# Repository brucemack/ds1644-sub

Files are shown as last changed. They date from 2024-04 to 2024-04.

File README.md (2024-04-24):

Overview
========
The goal of this project is to produce an adaptor board to allow a "modern" M48T35 NVRAM/RTC chip to be 
used where a
"vintage" DS1643/DS1644 used to be.  This is relevant for owners of S-COM
5K/6K/7K repeater controllers.  The old Dallas Semi parts are
hard to find in DIP format, and at this point their batteries are likely 
dead.

(Testing is still in process - more documentation will follow if this works.)

Here's what the board looks like:

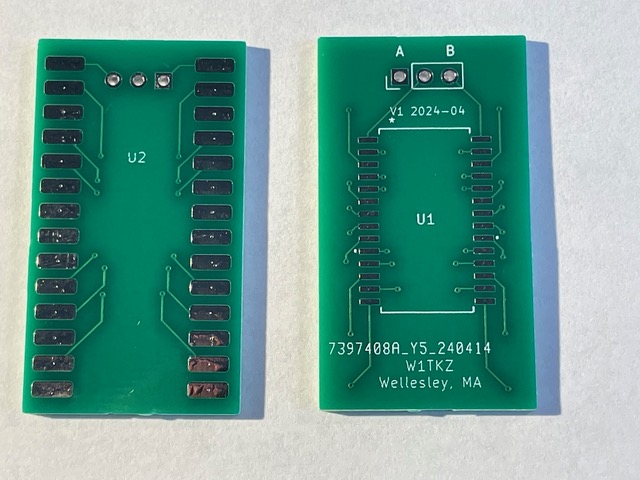
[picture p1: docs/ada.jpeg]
Adaptor


References
==========

* [M48T35 Datasheet](https://www.st.com/content/ccc/resource/technical/document/datasheet/group1/b6/56/b6/36/4d/38/4d/18/CD00000551/files/CD00000551.pdf/jcr:content/translations/en.CD000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)
* [DS1643 Datasheet](https://www.analog.com/media/en/technical-documentation/data-sheets/DS1643-DS1643P.pdf) - used in the 5K
* [DS1644 Datasheet](https://www.analog.com/media/cn/technical-documentation/data-sheets/2744.pdf) - used in the 7K

Photograph of DS1643 in an S-COM 5K to demonstrate that mechanical clearance isn't an issue around the chip.

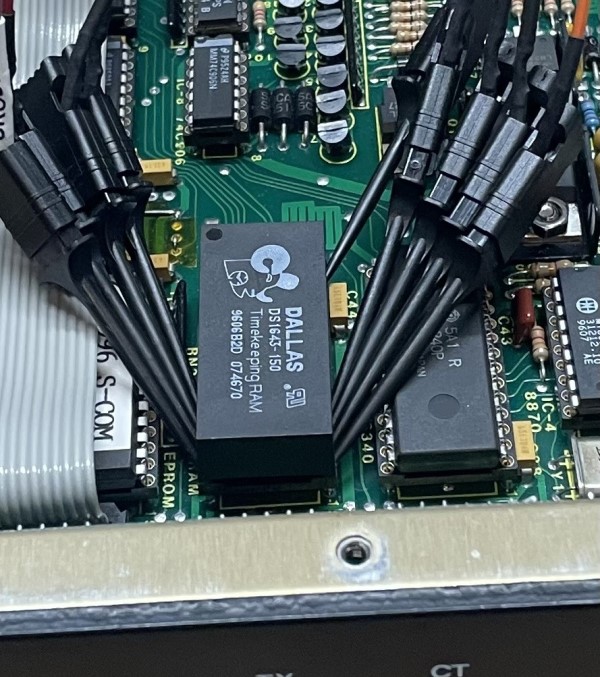
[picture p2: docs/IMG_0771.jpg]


Notes on Testing an Original DS1643
===================================

I have access to an S-COM 5K that has a DS1643 NVRAM/RTC chip in it. I've been using that 
to do some testing.  I pulled the DS1643 out of the controller and put it into my memory tester (see more detail on that below). 

The date code on the part is 1996.  It works fine!

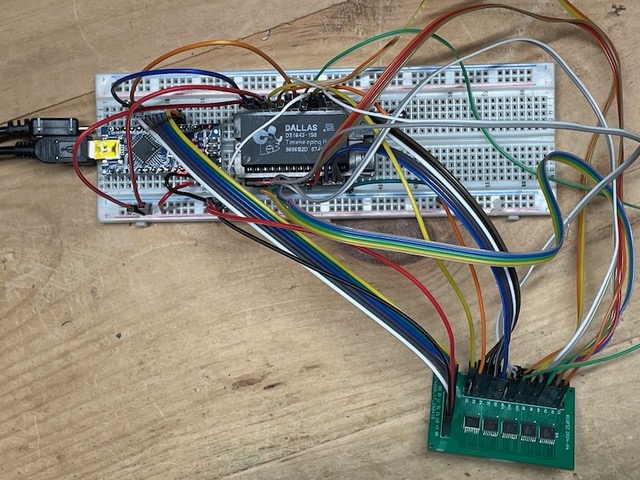
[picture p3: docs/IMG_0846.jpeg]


This chip is interesting in that the RTC is mapped into the 
very top few bytes of the NVRAM.  On the 8K part you need to read from locations 0x1ff9 to 0x1fff to get the time/date.  IMPORTANT: Remember that all numbers are in 
BCD format with the 1's digit in the low-order nibble and the 10's digit in the high-order nibble of each byte.

When I powered up the chip and read the time from the magic 
locations I was amazed to see that it was correct to within <2 hours after an unknown period
of time of non-use. Obviously, the battery is still good in this 
particular unit. :-)

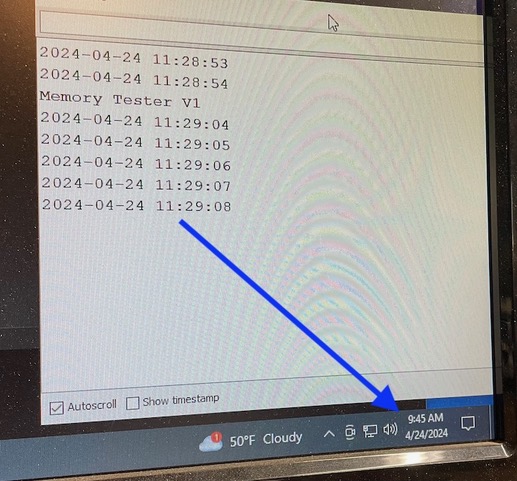
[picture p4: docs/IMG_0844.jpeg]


The S-COM 7K uses a 32K part. Everything should be the same,
except the memory map locations of the RTC are higher.

Notes Related to a Memory Tester
================================

A memory testing device was created to read/write/validate 5V RAM/PROM parts, along with any related adaptor boards. This could be used to test
that a chip/socket is working correctly or to make a copy of an NVRAM/EPROM/EEPROM. 

The tester can support 16 address lines, 8 bit-directional data lines, and three control lines (~OE, ~WE, ~CS, etc),
for a total of 27 signals.  Only 6 GPIO pins on a microcontroller are needed to drive the tester.

The testing cycle writes/reads different patterns into the 
memory chip to make sure there are no bad bits.

Here's what the tester PCB looks like:

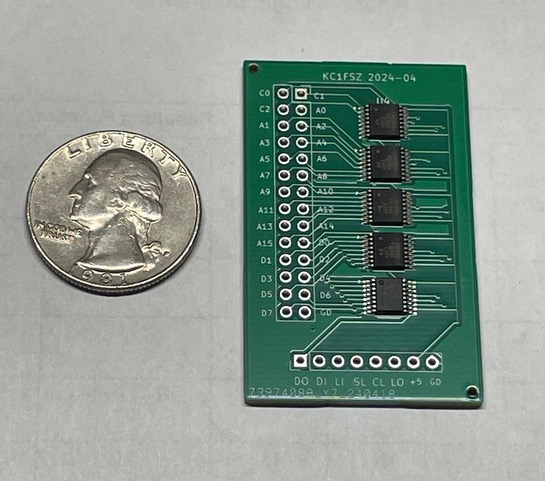
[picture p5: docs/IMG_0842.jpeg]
Tester1


Here it is wired into an Arduino Nano and a 28-pin ZIF socket
for testing:

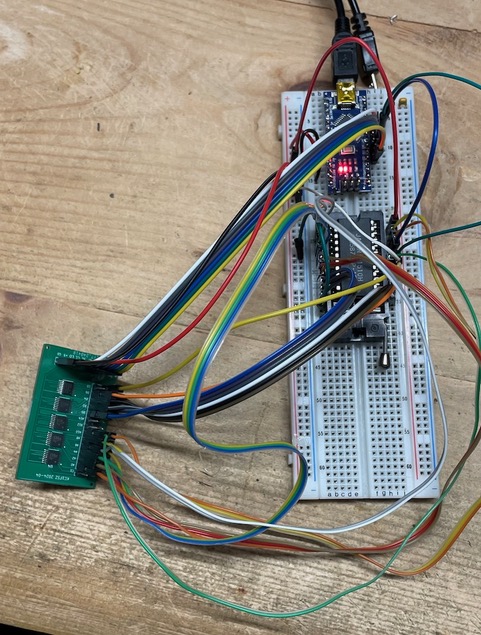
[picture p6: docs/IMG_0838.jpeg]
Tester2


Here's a vintage [Toshiba 2K SRAM chip](http://matthieu.benoit.free.fr/cross/data_sheets/TMM2016AP.pdf) that was tested successfully:

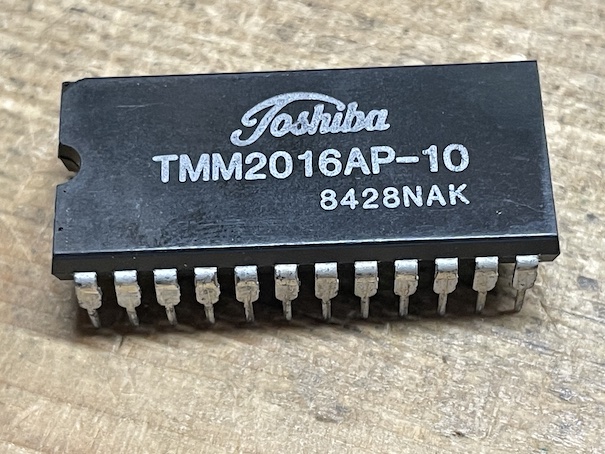
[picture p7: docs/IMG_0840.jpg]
SRAM


Judging from [this databook](http://www.bitsavers.org/components/toshiba/_dataBook/1983_Toshiba_MOS_Memory.pdf) an the date code
on that chip I'm assuming it's a 1984 part.  We've come a long
way in 40 years!

Tester Shift Register Chain Layout
----------------------------------
       
       |    Control     |   Address Low   |  Address High   |    Data Out     |   Data In      |
       +----------------+-----------------+-----------------+-----------------+----------------+
        C C C x x x x O   A A A A A A A A   A A A A A A A A   O O O O O O O O   I I I I I I I I  
        0 1 2         E   0 0 0 0 0 0 0 0   0 0 1 1 1 1 1 1   0 1 2 3 4 5 6 7   0 1 2 3 4 5 6 7
                          0 1 2 3 4 5 6 7   8 9 0 1 2 3 4 5

                                    =========== DATA FLOW ==========>    

Notes
* Data flows from left to right.
* There is no hand-off between O7 and I0.
* The high-order bit of the Control register (OE) controls the -OE of the Data Out register. So
you must write a zero into this bit when generating a write into a memory device.

Tester Control Interface
------------------------

(From left to right)

* Pin 1: Data Out - High-order bit out of the Data In register (i.e. I7 in the above diagram)
* Pin 2: Data In - Low-order bit into the Control register (i.e. C0 in the above diagram)
* Pin 3: Latch In (+) - Only relevant for the Data In register.  Rising edge locks the memory device output 
into the Data In register.  Make sure that shift/load is set to 1 before doing this.
* Pin 4: Shift/Load - Only relevant for the Data In register.  Issue a zero pulse after the Latch In clock
to move data into the shift register, preparing to shift out the data that was read.
* Pin 5: Clock (+) - Rising edge shifts one position to the right.  Make sure that shift/load is set to 0 before
doing this.
* Pin 6: Latch Out (+) - Rising edge makes the contents of the Control, Address Low, Address High, and Data Out
registers visible to the memory device.  
* Pin 7: 5V
* Pin 8: Ground

Copyright
=========

Copyright (C) 2024 - Bruce MacKinnon

This work is covered under the terms of the GNU Public License (V3). Please consult the LICENSE file for more information.

This work is being made available for non-commercial use. Redistribution, commercial use or sale of any part is prohibited.

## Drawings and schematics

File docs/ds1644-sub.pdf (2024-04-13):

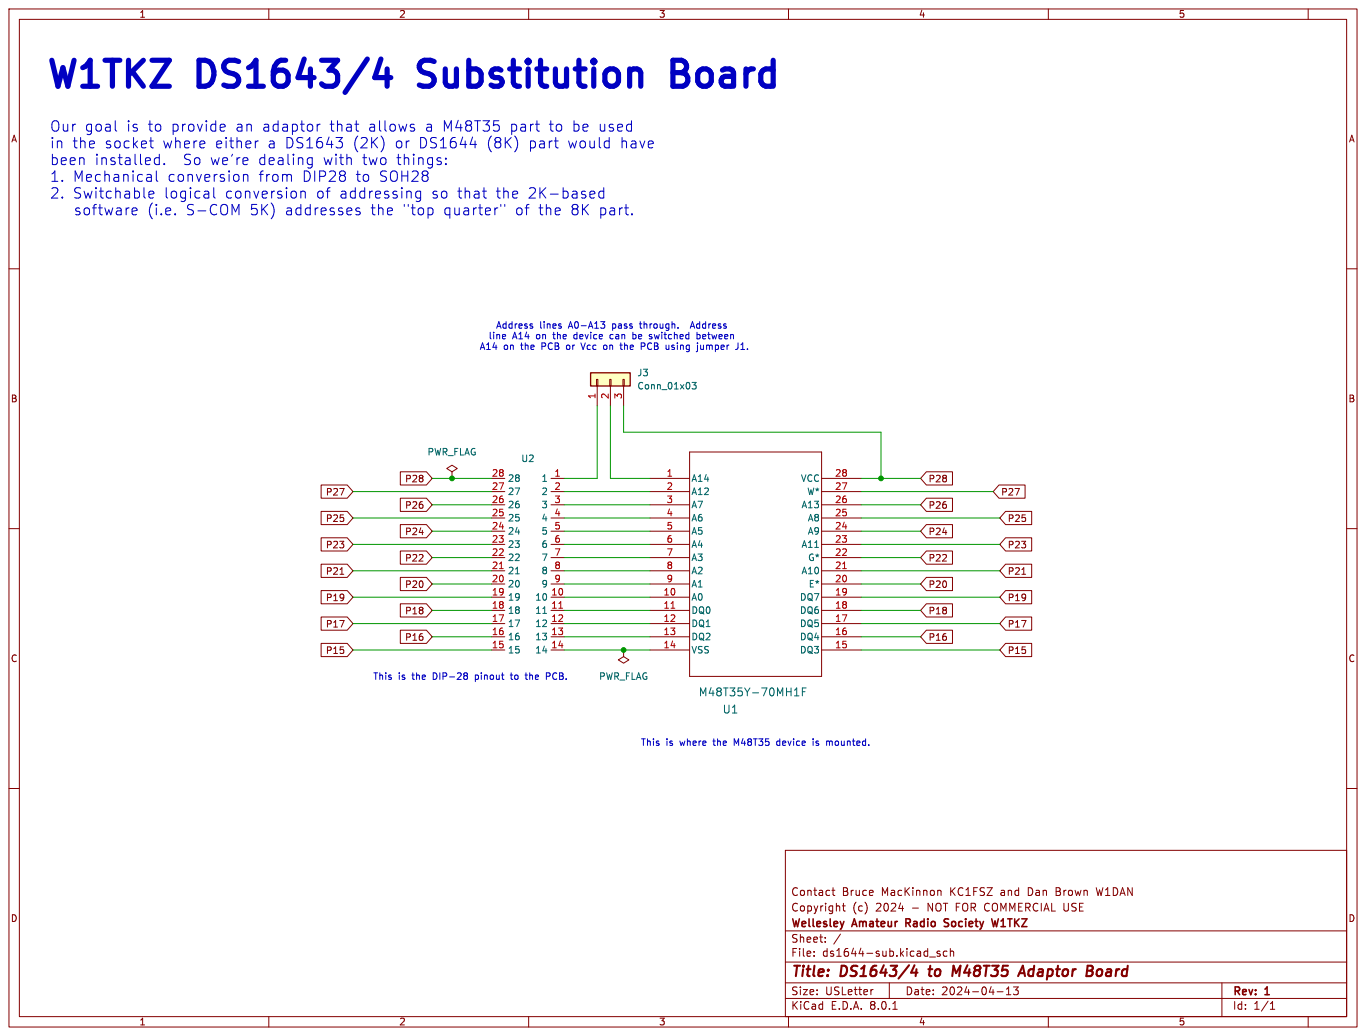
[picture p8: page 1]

Our goal is to provide an adaptor that allows a M48T35 part to be used
in the socket where either a DS1643 (2K) or DS1644 (8K) part would have

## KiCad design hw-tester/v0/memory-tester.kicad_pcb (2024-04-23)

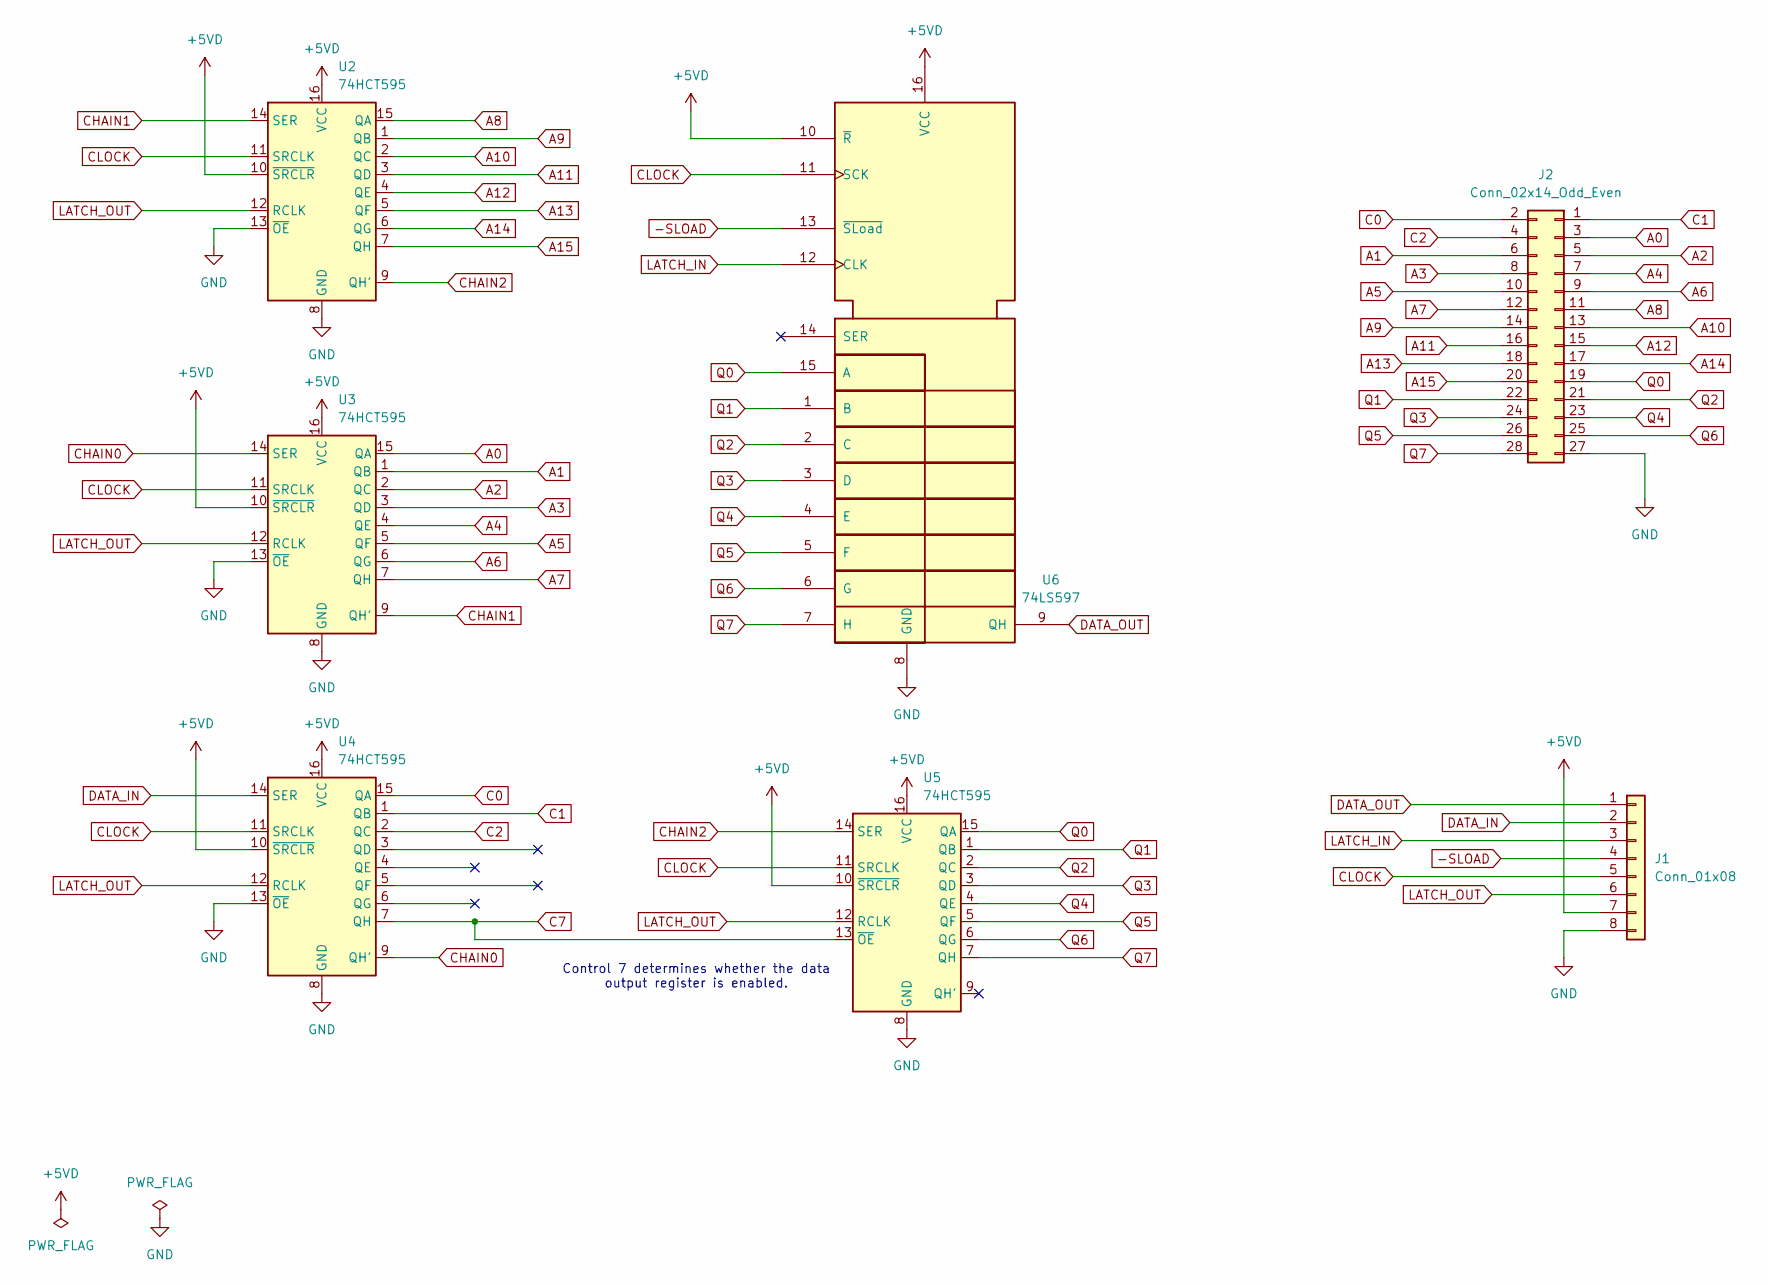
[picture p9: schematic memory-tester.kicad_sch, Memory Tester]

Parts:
J1: Conn_01x08; PinHeader_1x08_P2.54mm_Vertical
J2: Conn_02x14_Odd_Even; PinSocket_2x14_P2.54mm_Vertical
U2, U3, U4, U5: 74HCT595; TSSOP-16_4.4x5mm_P0.65mm; LCSC C273642
U6: 74LS597; TSSOP-16_4.4x5mm_P0.65mm; LCSC C5444304

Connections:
+5VD: J1.7, U2.10 (~SRCLR), U2.16 (VCC), U3.10 (~SRCLR), U3.16 (VCC), U4.10 (~SRCLR), U4.16 (VCC), U5.10 (~SRCLR), U5.16 (VCC), U6.10 (~R), U6.16 (VCC)
-SLOAD: J1.4, U6.13 (~SLoad)
A0: J2.3, U3.15 (QA)
A1: J2.6, U3.1 (QB)
A2: J2.5, U3.2 (QC)
A3: J2.8, U3.3 (QD)
A4: J2.7, U3.4 (QE)
A5: J2.10, U3.5 (QF)
A6: J2.9, U3.6 (QG)
A7: J2.12, U3.7 (QH)
A8: J2.11, U2.15 (QA)
A9: J2.14, U2.1 (QB)
A10: J2.13, U2.2 (QC)
A11: J2.16, U2.3 (QD)
A12: J2.15, U2.4 (QE)
A13: J2.18, U2.5 (QF)
A14: J2.17, U2.6 (QG)
A15: J2.20, U2.7 (QH)
C0: J2.2, U4.15 (QA)
C1: J2.1, U4.1 (QB)
C2: J2.4, U4.2 (QC)
C7: U4.7 (QH), U5.13 (~OE)
CHAIN0: U3.14 (SER), U4.9 (QH')
CHAIN1: U2.14 (SER), U3.9 (QH')
CHAIN2: U2.9 (QH'), U5.14 (SER)
CLOCK: J1.5, U2.11 (SRCLK), U3.11 (SRCLK), U4.11 (SRCLK), U5.11 (SRCLK), U6.11 (SCK)
DATA_IN: J1.2, U4.14 (SER)
DATA_OUT: J1.1, U6.9 (QH)
GND: J1.8, J2.27, U2.8 (GND), U2.13 (~OE), U3.8 (GND), U3.13 (~OE), U4.8 (GND), U4.13 (~OE), U5.8 (GND), U6.8 (GND)
LATCH_IN: J1.3, U6.12 (CLK)
LATCH_OUT: J1.6, U2.12 (RCLK), U3.12 (RCLK), U4.12 (RCLK), U5.12 (RCLK)
Q0: J2.19, U5.15 (QA), U6.15 (A)
Q1: J2.22, U5.1 (QB), U6.1 (B)
Q2: J2.21, U5.2 (QC), U6.2 (C)
Q3: J2.24, U5.3 (QD), U6.3 (D)
Q4: J2.23, U5.4 (QE), U6.4 (E)
Q5: J2.26, U5.5 (QF), U6.5 (F)
Q6: J2.25, U5.6 (QG), U6.6 (G)
Q7: J2.28, U5.7 (QH), U6.7 (H)

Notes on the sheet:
Control 7 determines whether the data output register is enabled.

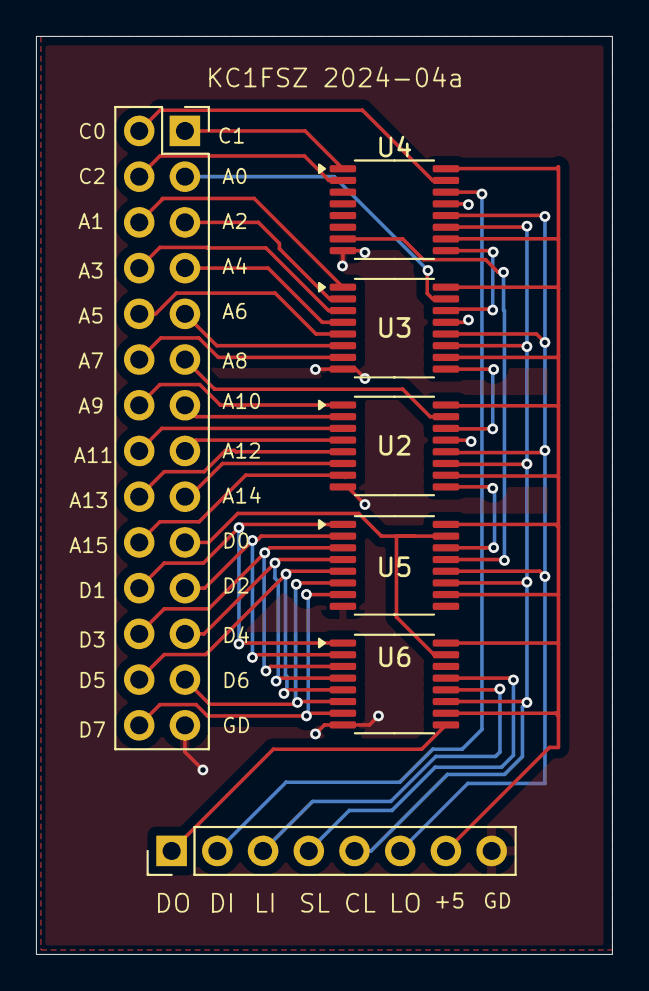
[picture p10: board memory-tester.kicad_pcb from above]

Board: 2 copper layers, 32.0 x 51.0 mm, 7 parts (0 on the bottom side), 39 nets.

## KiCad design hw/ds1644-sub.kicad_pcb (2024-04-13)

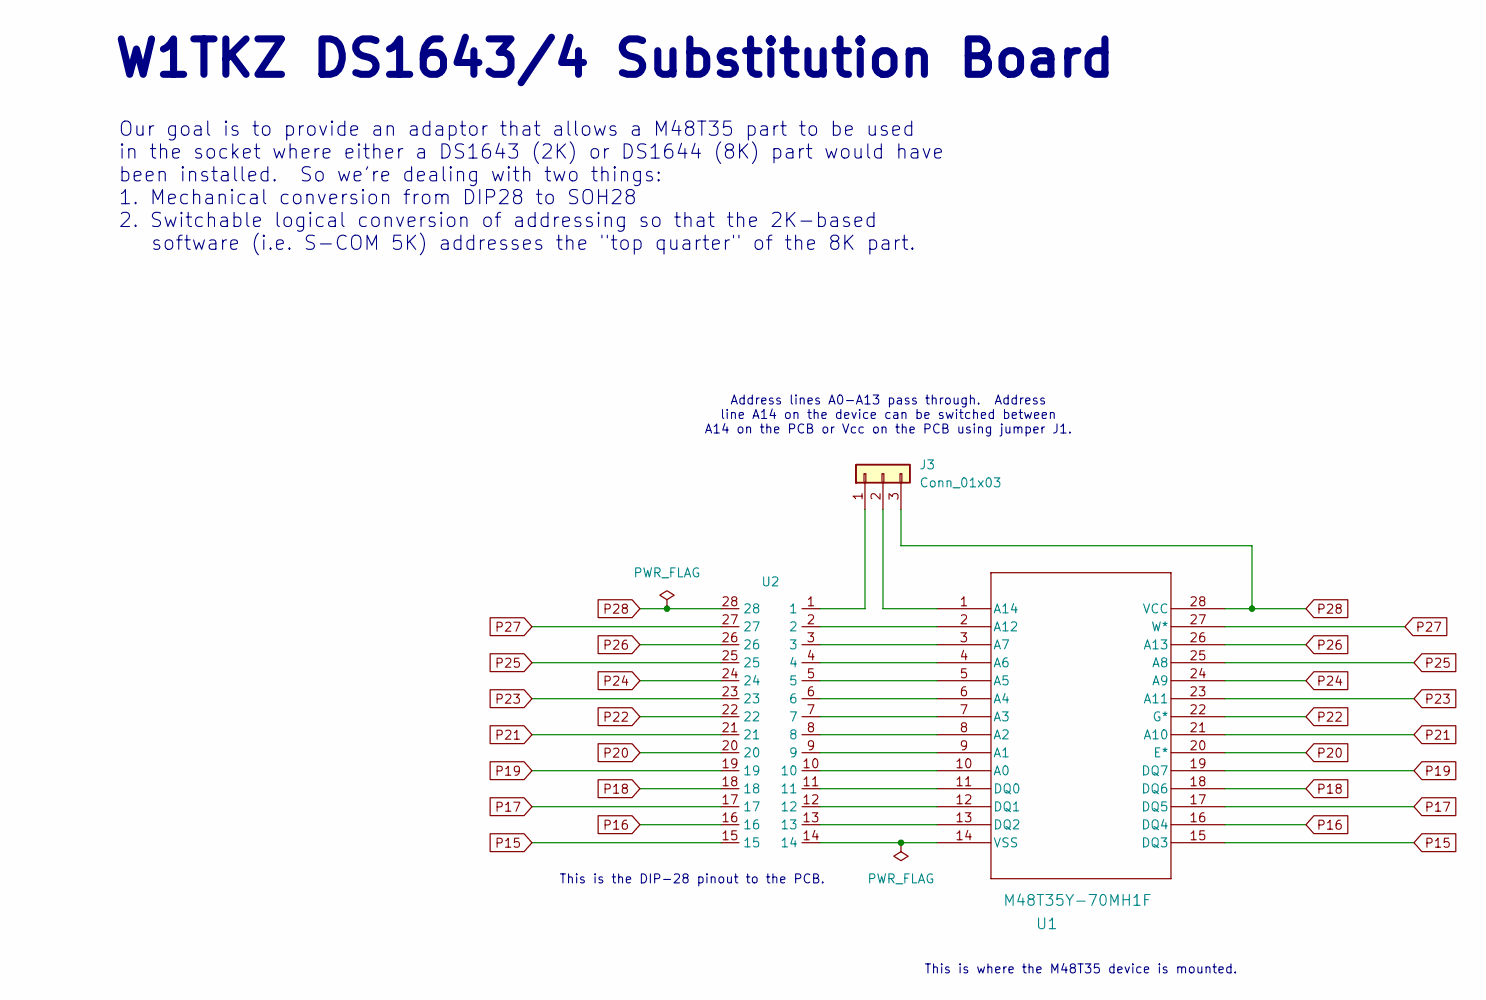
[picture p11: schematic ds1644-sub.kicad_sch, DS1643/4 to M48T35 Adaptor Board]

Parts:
J3: Conn_01x03; PinHeader_1x03_P2.54mm_Vertical
U1: M48T35Y-70MH1F; SOH28_STM
U2: DIP-28-SMD

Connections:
unnamed: J3.1, U2.1
unnamed: J3.2, U1.1 (A14)
unnamed: U1.10 (A0), U2.10
unnamed: U1.9 (A1), U2.9
unnamed: U1.8 (A2), U2.8
unnamed: U1.7 (A3), U2.7
unnamed: U1.6 (A4), U2.6
unnamed: U1.5 (A5), U2.5
unnamed: U1.4 (A6), U2.4
unnamed: U1.3 (A7), U2.3
unnamed: U1.2 (A12), U2.2
unnamed: U1.11 (DQ0), U2.11
unnamed: U1.12 (DQ1), U2.12
unnamed: U1.13 (DQ2), U2.13
unnamed: U1.14 (VSS), U2.14
P15: U1.15 (DQ3), U2.15
P16: U1.16 (DQ4), U2.16
P17: U1.17 (DQ5), U2.17
P18: U1.18 (DQ6), U2.18
P19: U1.19 (DQ7), U2.19
P20: U1.20 (E*), U2.20
P21: U1.21 (A10), U2.21
P22: U1.22 (G*), U2.22
P23: U1.23 (A11), U2.23
P24: U1.24 (A9), U2.24
P25: U1.25 (A8), U2.25
P26: U1.26 (A13), U2.26
P27: U1.27 (W*), U2.27
P28: J3.3, U1.28 (VCC), U2.28

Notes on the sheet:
W1TKZ DS1643/4 Substitution Board
Our goal is to provide an adaptor that allows a M48T35 part to be used in the socket where either a DS1643 (2K) or DS1644 (8K) part would have been installed. So we're dealing with two things: 1. Mechanical conversion from DIP28 to SOH28 2. Switchable logical conversion of addressing so that the 2K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
This is where the M48T35 device is mounted.
Address lines A0-A13 pass through. Address line A14 on the device can be switched between A14 on the PCB or Vcc on the PCB using jumper J1.
This is the DIP-28 pinout to the PCB.

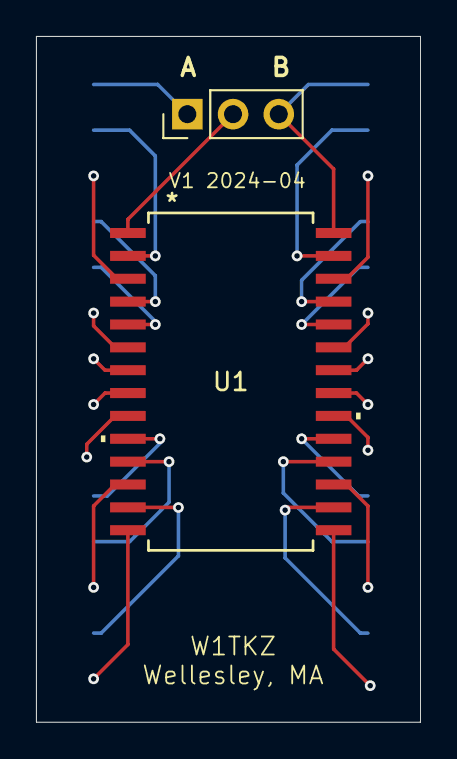
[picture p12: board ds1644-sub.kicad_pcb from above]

Board: 2 copper layers, 21.3 x 38.1 mm, 3 parts (1 on the bottom side), 29 nets.

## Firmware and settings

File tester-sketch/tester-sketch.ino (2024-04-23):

/**
 * Copyright (C) 2024, Bruce MacKinnon KC1FSZ
 *
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
 * FOR AMATEUR RADIO USE ONLY.
 * NOT FOR COMMERCIAL USE WITHOUT PERMISSION.
 */
#define PIN_DATA_OUT (2)
#define PIN_DATA_IN (3)
#define PIN_LATCH_IN (4)
#define PIN_SHIFT_LOAD (5)
#define PIN_CLOCK (6)
#define PIN_LATCH_OUT (7)
#define PIN_LED (13)

// TEMP: DUE TO HW BUG
#define PIN_MEM_OE (8)
#define PIN_MEM_WE (9)

/*
 * Shifts 32 bits into the control, address (2), and data registers.
 */
void writeRaw(uint32_t v) {
  // Shift each bit into the ring
  for (int i = 0; i < 32; i++) {  
    // Setup a data bit
    digitalWrite(PIN_DATA_IN, (v & 0x80000000) ? 1 : 0);
    // Shift clock
    digitalWrite(PIN_CLOCK, 1);
    digitalWrite(PIN_CLOCK, 0);
    // Rotate 
    v = v << 1;

    // TEMP (DUE TO HARDWARE BUG)
    // Latch out
    digitalWrite(PIN_LATCH_OUT, 1);
    digitalWrite(PIN_LATCH_OUT, 0);   
  }
  // Latch out
  //digitalWrite(PIN_LATCH_OUT, 1);
  //digitalWrite(PIN_LATCH_OUT, 0);   
}

uint8_t readRaw() {
  // Load parallel data into latch
  digitalWrite(PIN_LATCH_IN, 1);
  digitalWrite(PIN_LATCH_IN, 0);     
  // Transfer latch data to shift register
  digitalWrite(PIN_SHIFT_LOAD, 0);
  // Prepare to start shifting
  digitalWrite(PIN_SHIFT_LOAD, 1);
  uint8_t result = 0;
  // Shift each bit from the ring
  for (int i = 0; i < 8; i++) {
    // Rotate
    result = result << 1;  
    if (digitalRead(PIN_DATA_OUT) == HIGH)
      result |= 1;
    // Shift clock
    digitalWrite(PIN_CLOCK, 1);
    digitalWrite(PIN_CLOCK, 0);
  }
  return result;
}

void writeMem(uint16_t addr, uint8_t data) {
  // OE=0
  uint32_t ring = ((uint32_t)addr << 8) | ((uint32_t)data << 24);
  writeRaw(ring);
  // Strobe ~WE
  digitalWrite(PIN_MEM_WE, 0);
  digitalWrite(PIN_MEM_WE, 1);  
}

uint8_t readMem(uint16_t addr) {
  // OE=1 to prevent the Data Out register from interfering
  uint32_t ring = ((uint32_t)addr << 8) | (0b10000000);
  writeRaw(ring);
  // Enable memory output
  digitalWrite(PIN_MEM_OE, 0);
  delay(1);
  // Read back
  uint8_t r = readRaw();
  // Disable memory output
  digitalWrite(PIN_MEM_OE, 1);  
  return r;
}

void setup() {

  // Console
  Serial.begin(9600);

  pinMode(PIN_LED, OUTPUT);
  pinMode(PIN_DATA_OUT, INPUT);
  pinMode(PIN_DATA_IN, OUTPUT);
  pinMode(PIN_LATCH_IN, OUTPUT);
  digitalWrite(PIN_LATCH_IN, 0);
  pinMode(PIN_SHIFT_LOAD, OUTPUT);
  digitalWrite(PIN_SHIFT_LOAD, 1);
  pinMode(PIN_CLOCK, OUTPUT);
  digitalWrite(PIN_CLOCK, 0);
  pinMode(PIN_LATCH_OUT, OUTPUT);
  digitalWrite(PIN_LATCH_OUT, 0);

  // TEMP: WILL BE MOVED TO CONTROL REGISTER
  pinMode(PIN_MEM_OE, OUTPUT);
  digitalWrite(PIN_MEM_OE, 1);
  pinMode(PIN_MEM_WE, OUTPUT);
  digitalWrite(PIN_MEM_WE, 1);
  // TEMP: WILL BE MOVED TO CONTROL REGISTER

  // Diag
  digitalWrite(PIN_LED, 1);
  delay(500);
  digitalWrite(PIN_LED, 0);
  delay(500);
  digitalWrite(PIN_LED, 1);

  Serial.println("Memory Tester V0");

  uint16_t space = 2048;
  Serial.print("Checking ");
  Serial.print(space);
  Serial.println(" locations ...");
  
  bool failed = false;
  for (uint16_t a = 0; a < space; a++) {
    writeMem(a, 0x55);
    uint8_t t0 = readMem(a);
    writeMem(a, 0xaa);
    uint8_t t1 = readMem(a);
    if (t0 != 0x55 || t1 != 0xaa) {
      Serial.print("Bad location: ");
      Serial.println(a);
      failed = true;
      break;  
    }
  }
  for (uint16_t a = 0; a < space; a++)
    writeMem(a, a);
  for (uint16_t a = 0; a < space; a++)
    if (readMem(a) != (a & 0xff)) {
      Serial.print("Bad location: ");
      Serial.println(a);
      failed = true;
      break;        
    } 
  if (!failed) {
    Serial.println("No faults detected");
  }
}

void loop() {
  /*  
  // Write a C0=1, disable OE
  writeRaw(0b110000000);
  // Read back
  uint32_t r = readRaw();
  Serial.print(r);
  Serial.println();
  delay(1000);
  
  // Write a C0=0, disable OE
  writeRaw(0b010000000);
  // Read back
  r = readRaw();
  Serial.print(r);
  Serial.println();
  delay(1000);
  */
  /*
  // Internal self-test
  // Show that we can latch data out and read it back
  // Write DO=0x55, enable OE
  writeRaw(0x00ff0000);
  // Read back
  uint32_t r = readRaw();
  Serial.print(r);
  Serial.println();
  delay(1000);
  
  // Write DO=0xaa, enable OE
  writeRaw(0x00000000);
  // Read back
  r = readRaw();
  Serial.print(r);
  Serial.println();
  delay(1000);
  */
}

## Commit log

2024-04-22 Added docs for tester
    [memory-tester.kicad_pcb, memory-tester.kicad_sch]
2024-04-23 Tester is working (with SW work-around for HW bug)
    [tester-sketch.ino]
2024-04-23 Cleaned up a HW bug in the tester, provided docs
    [memory-tester.kicad_pcb, memory-tester.kicad_sch]

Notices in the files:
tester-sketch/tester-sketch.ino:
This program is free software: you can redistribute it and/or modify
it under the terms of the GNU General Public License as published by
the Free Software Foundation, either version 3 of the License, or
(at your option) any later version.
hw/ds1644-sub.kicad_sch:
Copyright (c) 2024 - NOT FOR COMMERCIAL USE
